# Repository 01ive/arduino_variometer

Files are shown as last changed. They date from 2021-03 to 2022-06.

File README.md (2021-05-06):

# Arduino variometer

Mini Paragliding variometer based on Arduino technology.

Aim of this project is to have the smallest and cheapest paragliding variometer.
Mechanical fixation will be realized using action cam standard allowing tones of fixing possibilityes.

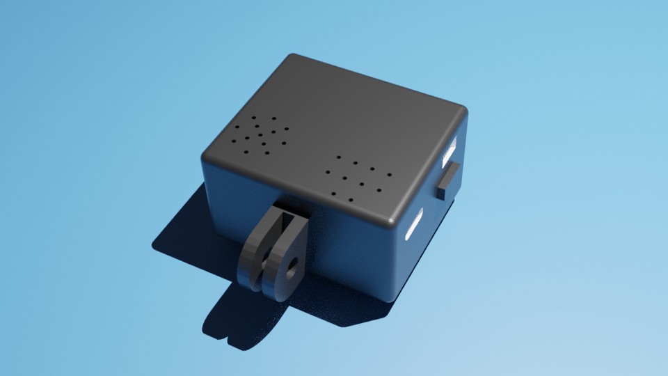
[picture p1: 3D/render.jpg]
circuit


-----------------------------------------------------------------------

## Component and prices

* Arduino Nano Atmega328 *[4.33€]*
* Piezo Buzzer passive *[2.49€]*
* BMP280 sensor *[2.66€]*
* Batterie Shield *[2.99€]*
* Battery *[12.23€]*
* Switch On/Off *[0.28€]*
* I2c DC - DC adapter *[0.80€]*

Total Price **25.78€**

-----------------------------------------------------------------------

## Software environnment

* arduino-1.8.13 IDE
* Visual code 1.53
    * vsciot-vscode.vscode-arduino
    * ms-vscode.cpptools
* blender 2.80
* fritzing.0.8.7b.pc
* fritzing library https://github.com/adafruit/Fritzing-Library

-----------------------------------------------------------------------

## Schematics

### Representative prototype

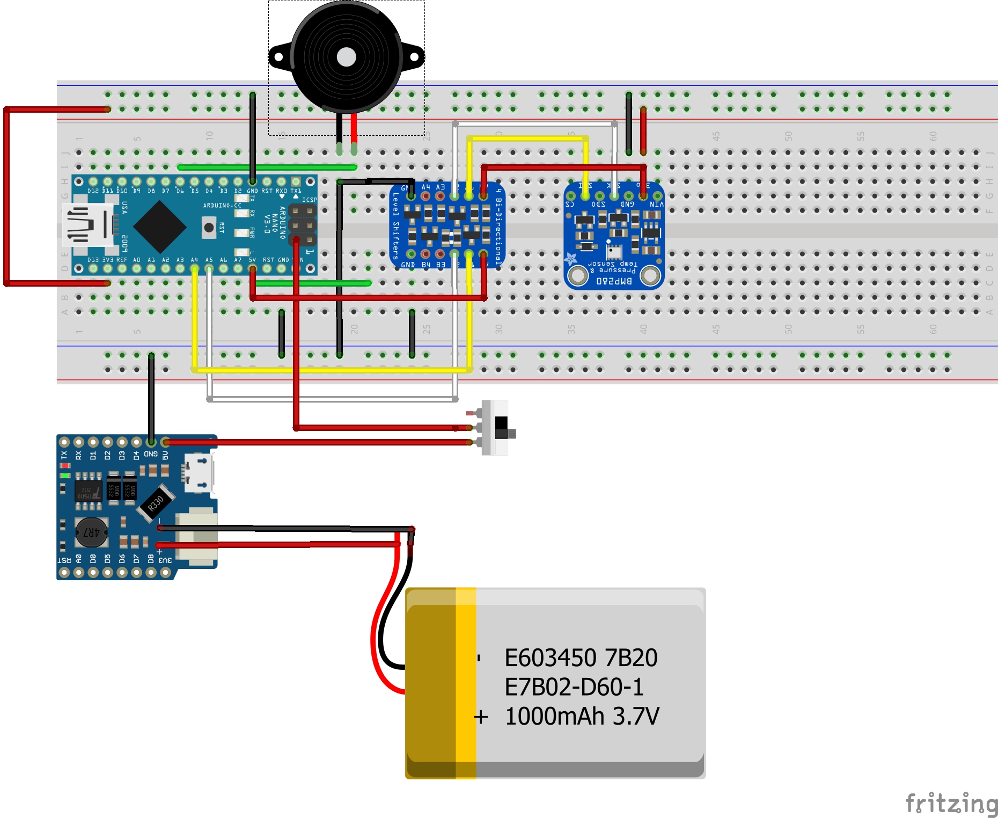
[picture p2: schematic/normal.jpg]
normal


### Schematic

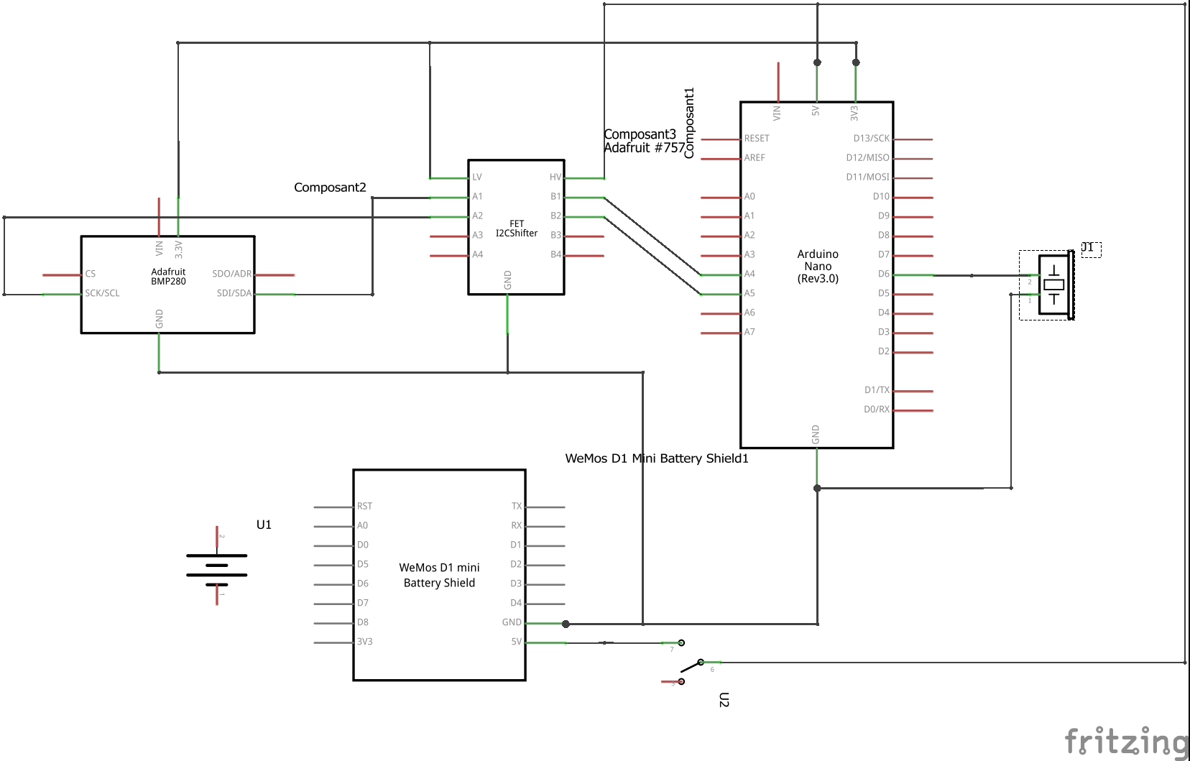
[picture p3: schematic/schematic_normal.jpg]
schem


-----------------------------------------------------------------------

## Mechanic

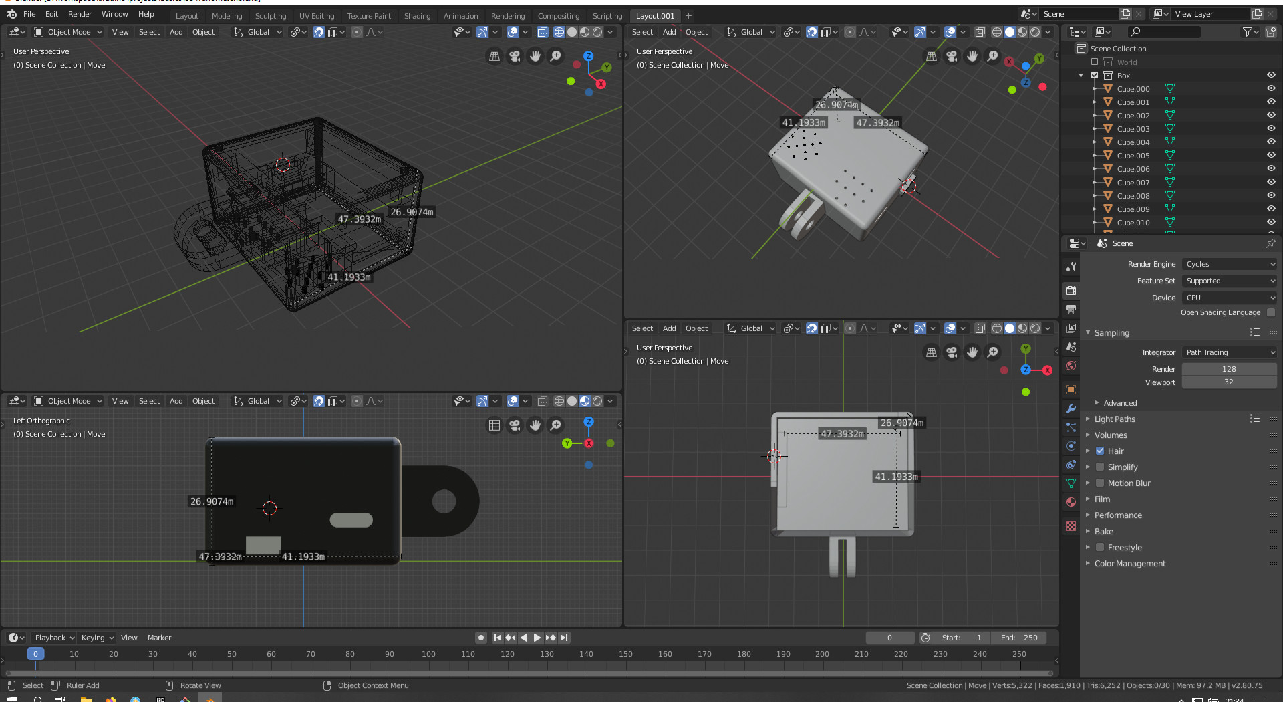
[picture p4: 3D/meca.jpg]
meca


-----------------------------------------------------------------------

## Callibration mode

Software allows debug and callibration modes

### Serial mode

Using USB serial console to print information. Buzzers are disabled quiet mode.

Uncomment ```#define DEBUG 1``` to activate.

### Sound setup

In order to test and found best suitable sound you can use these mode and serial debug link to test buzzer sound.

Uncomment ```#define SOUND_TEST 1``` to activate.

-----------------------------------------------------------------------

## docs

BMP280
https://cdn-shop.adafruit.com/datasheets/BST-BMP280-DS001-11.pdf

MPU6056
https://invensense.tdk.com/wp-content/uploads/2015/02/MPU-6000-Datasheet1.pdf

Nano pinout 
https://content.arduino.cc/assets/Pinout-NANO_latest.pdf

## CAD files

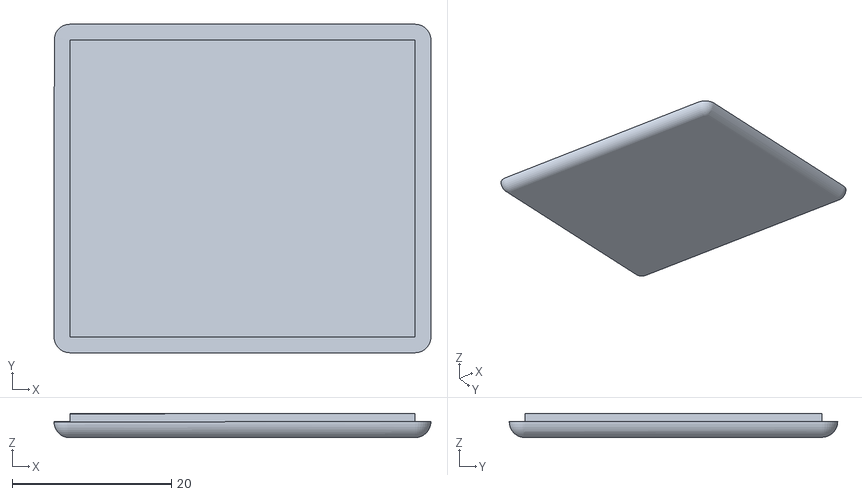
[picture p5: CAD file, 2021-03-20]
3D/cover.stl
47.4 x 41.3 x 3.06

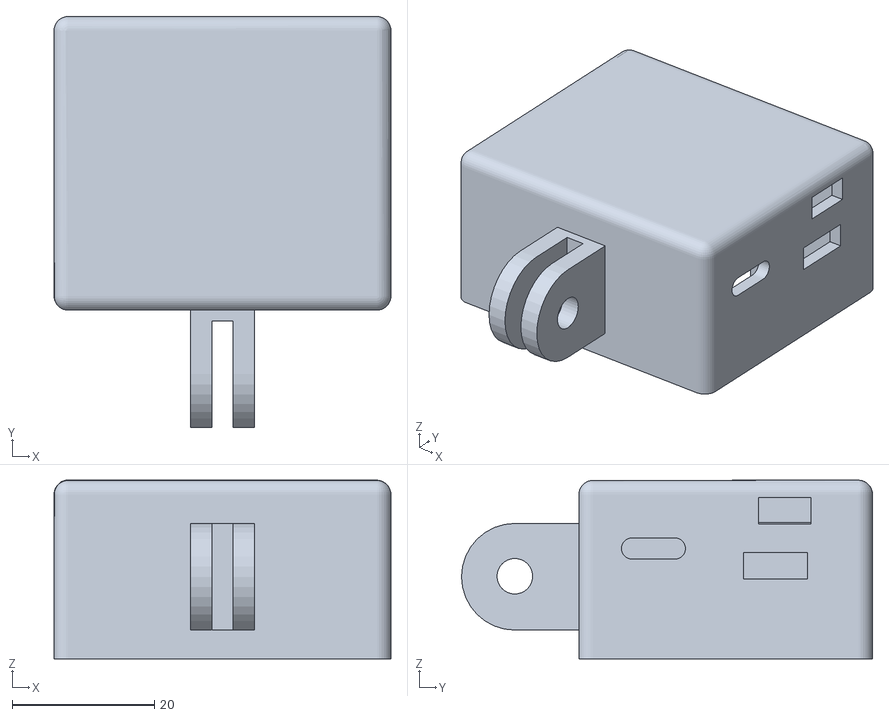
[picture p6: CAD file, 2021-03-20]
3D/box.stl
47.4 x 57.8 x 25.1

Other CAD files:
3D/variometer.blend

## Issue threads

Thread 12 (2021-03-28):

Add 3.3 V power up to 5 V to power arduino

01ive, 2021-03-28:

01ive, 2021-03-28:
https://cdn-shop.adafruit.com/datasheets/BST-BMP280-DS001-11.pdf

5Volts can destroy sensor

Closed 2021-05-03.

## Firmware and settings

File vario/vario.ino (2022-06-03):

#include "buzzer.h"
#include "pressure_sensor.h"

#define VARIO_NBR_OF_BIPS 7

// https://www.lebipbip.com/fr/paragliding_variometer_explained/
const Buzzer::t_buzzer_sound bips_down =                  {800, 1000, 100};  // Down
const Buzzer::t_buzzer_sound bips[VARIO_NBR_OF_BIPS] = {  {800, 300, 100},   // 0
                                                          {600, 300, 220},   // Up 1st level
                                                          {400, 200, 240},   // Up 2nd level
                                                          {300, 150, 260},   // Up 3rd level
                                                          {200, 100, 280},   // Up 4th level
                                                          {200, 100, 300},   // Up 5th level
                                                          {200, 100, 300} }; // Up 6th level

Buzzer::t_buzzer_sound current_bip;

// Constants settings for variometer
const float sampling_period = 100;
const float speed_sensibility_up = 0.5;
const float speed_sensibility_down = -2;

// Objects
TwoWire I2c;
Pressure_Sensor pressure(&I2c);
Buzzer buzzer;

// Global var
float current_altitude = 0;
float previous_altitude = 0;
float vertical_speed = 0;
float current_time = 0;
float previous_time = 0;

Buzzer::t_buzzer_sound getSound(float speed) {
  Buzzer::t_buzzer_sound bip;
  float vertical_speed_float = 0;
  int vertical_speed_int = 0;

  if( speed > 0 ) {
    vertical_speed_int = (int)speed;
    vertical_speed_float = vertical_speed_int - speed;

    if( vertical_speed_int >= VARIO_NBR_OF_BIPS) {
      vertical_speed_int = VARIO_NBR_OF_BIPS - 1;
      vertical_speed_float = 0;
    }

    bip = bips[vertical_speed_int];

    bip.bip_duration -= (bips[vertical_speed_int].bip_duration - bips[vertical_speed_int+1].bip_duration) * vertical_speed_float;
    bip.bip_note += (bips[vertical_speed_int].bip_note - bips[vertical_speed_int+1].bip_note) * vertical_speed_float;
    bip.duration -= (bips[vertical_speed_int].duration - bips[vertical_speed_int+1].duration) * vertical_speed_float;
  } else {
    bip = bips_down;
    if(speed < -5) {
      speed = -5;
    }
    bip.bip_note += (10 * speed);
  }

  return bip;
}

// Setup function
void setup() {

  if( pressure.start_up() == Pressure_Sensor::PRESSURE_SENSOR_OK ) {
      buzzer.startup();
  }
  else {
      while(1) {
        buzzer.repeat_sound(&bips[0]);
        buzzer.sound_tick();
        delay(500);
      }
  }  
  previous_altitude = pressure.readAltitude();
}

// Infinite loop
void loop() {
  float delta_altitude;
  float delta_time;

  // Calculate vertical speed
  current_altitude = pressure.readAltitude();
  delta_altitude = current_altitude - previous_altitude;
  current_time = millis();
  delta_time = current_time - previous_time;
  vertical_speed = delta_altitude*(1000/delta_time);
    
  if (vertical_speed >= speed_sensibility_up) {
    current_bip = getSound(vertical_speed);
    buzzer.repeat_sound(&current_bip);
  }
  else if (vertical_speed <= speed_sensibility_down) {
    current_bip = getSound(vertical_speed);
    buzzer.repeat_sound(&current_bip);
  }
  else {
    buzzer.stop_sound();
  }

  previous_altitude = current_altitude;
  previous_time = current_time;
  buzzer.sound_tick();
  delay(sampling_period);
}

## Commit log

2021-02-14 First pressure read
2021-02-28 Change filter setup
2021-03-01 Change pressure error management
    [vario.ino]
2021-03-06 Add 3D model
    [variometer.blend]
2021-03-06 First meca proto
    [variometer.blend]
2021-03-07 Add schematics
    [Untitled Sketch.fzz]
2021-03-11 Work on meca
    [variometer.blend]
2021-03-13 Correct Up down sound
    [vario.ino]
2021-03-14 Update mechanic and create final schematic
    [Untitled Sketch.fzz, variometer.blend]
2021-03-14 Add STL file for 3D print
    [box.stl, cover.stl, variometer.blend]
2021-03-14 Correct bug on pressure sensor height (mechanics is finer)
    [box.stl, cover.stl, variometer.blend]
2021-03-18 add power switch
    [box.stl, cover.stl, variometer.blend]
2021-03-18 Prepare slicing
    [box.stl, cover.stl, variometer.blend]
2021-03-20 Rework meca to generate stl compatible with slicing tool
    [box.stl, cover.stl, variometer.blend]
2021-03-21 Start to implement sound according to velocity
2021-05-03 First test temp ok but no pressure
2021-05-03 First working pressure and accel
2021-05-03 Manage accel sensor
2021-05-03 Change sound setup and pressure filter
2021-05-06 Update Readme and schematics
    [Untitled Sketch.fzz]
2021-08-28 Change debug print
2022-06-03 Highly improve sensibility (but increase power consumption)
